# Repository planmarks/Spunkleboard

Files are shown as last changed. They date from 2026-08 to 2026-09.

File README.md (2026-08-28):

# Spunkleboard

**Spunkleboard** is a compact, hackable **ESP32-C3 / ESP32-C5 development board** with everything you
need for portable, interactive projects built in: **6 buttons**, a **0.96" OLED display**, an
onboard **LiPo battery** with charging, and an **SMA antenna connector** for serious wireless range.

It's a blank canvas. Flash it with whatever you like — the hardware is general-purpose and
firmware-agnostic. **Pre-made firmwares are coming soon.**

---

## ✨ Highlights

- 🧠 **ESP32-C3 / ESP32-C5** RIS-V Wi-Fi + Bluetooth LE SoC
- 🕹️ **6 tactile buttons** — a full directional + action pad for menus, games, and UIs
- 🖥️ **0.96" 128×64 OLED** (SSD1306/SSD1315, I²C) — crisp monochrome graphics and text
- 🔋 **Onboard LiPo battery + charging** — go fully untethered
- 📡 **SMA connector** — attach an external antenna for extended Wi-Fi/BLE (and sub-GHz on C5) range
- 🔌 **USB-C** for programming, power, and serial
- 🧩 **Firmware-agnostic** — Arduino, ESP-IDF, MicroPython, and more

---

## 🛠️ Hardware Overview

| Component | Details |
|---|---|
| **MCU module** | Seeed XIAO ESP32-C3 or ESP32-C5 (RISC-V, Wi-Fi + BLE) |
| **Display** | 0.96" OLED, 128×64, monochrome, I²C (`0x3C`) |
| **Buttons** | 6× momentary tactile switches (e.g. Up / Down / Left / Right / OK / Back) |
| **Power** | Single-cell LiPo with onboard charging via USB-C |
| **Antenna** | SMA connector for an external antenna |
| **Interface** | USB-C (power / flashing / serial), exposed GPIO |

> The board accepts the pin-compatible **XIAO ESP32-C3** and **ESP32-C5** modules, so you can pick
> the SoC that fits your project. The C5 adds dual-band Wi-Fi (2.4 + 5 GHz), which pairs nicely with
> the SMA antenna option.

---

## Button Wiring

| Function | Button | XIAO pin | GPIO |
|---|---|---|---|
| Up / Feed | UP | D0 | 1  |
| Down / Play | DOWN  | D1 | 0  |
| OK / Pet | OK | D2 | 25 |
| Back | BACK  | D3 | 7  |
| Left (screen)  | LEFT  | D8 | 8  |
| Right (screen) | RIGHT | D9 | 9  |

---

## 💡 What You Can Build

Because it's just a well-equipped ESP32 board, the possibilities are wide open:

- 📶 **Wi-Fi / BLE tools** — scanners, signal meters, and network utilities (great with the SMA antenna)
- 🎮 **Handheld games & toys** — the 6-button pad + OLED make a natural tiny game console
- 📟 **Portable dashboards** — sensor readouts, clocks, timers, notifiers
- 🏠 **Remote controls & IoT nodes** — battery-powered, wireless, pocket-sized
- 🧪 **Learning & prototyping** — a friendly platform for exploring embedded development
- 🎛️ **Menu-driven gadgets** — anything that benefits from a screen and buttons

---

## 🚀 Getting Started

### 1. Install a toolchain

**Arduino IDE**
1. Add the ESP32 board package (Espressif) via **Boards Manager**.
2. Select the matching **XIAO ESP32-C3** or **XIAO ESP32-C5** board.
3. Install a display library such as **U8g2** for the OLED.

**ESP-IDF** (advanced)
- Set the target with `idf.py set-target esp32c3` (or `esp32c5`) and build/flash as usual.

### 2. Flash

1. Connect the board over **USB-C**.
2. Select the correct serial port.
3. Upload your sketch/firmware. If needed, hold the module's **BOOT** button while connecting to
   enter download mode.

### 3. Hello, board

A first sketch typically:
- Brings up the OLED over I²C (`Wire.begin()`),
- Reads the 6 buttons (configured as `INPUT_PULLUP`, active-LOW),
- Draws a simple menu you can navigate.

---

## 🎛️ Using the Peripherals

- **Buttons** are wired between a GPIO and GND — enable the internal pull-ups (`INPUT_PULLUP`) and
  treat a LOW reading as "pressed."
- **OLED** is on the default I²C bus (SDA/SCL); most 0.96" modules use address `0x3C`.
- **LiPo battery** charges from USB-C; use a protected single-cell pack and mind polarity.
- **SMA antenna** connects to the module's RF path — fit an antenna rated for your band (2.4 GHz for
  C3; 2.4/5 GHz for C5) before transmitting.

> Exact GPIO assignments depend on your board revision and chosen module — check the silkscreen and
> your board's pin map, and consult the Seeed XIAO pin-multiplexing reference for the module you use.

---

## 📦 Firmware

**Pre-made firmwares are coming soon** — ready-to-flash images that showcase what Spunkleboard can do
out of the box. Until then, bring your own: any ESP32-C3/C5 project that uses an I²C OLED, GPIO
buttons, and (optionally) the battery and antenna will run happily here.

Want to share what you've built? Contributions and firmware submissions are welcome.

---

## 🤝 Contributing

Issues, ideas, hardware notes, and firmware contributions are all welcome. Open an issue or a pull
request to get involved.

---

## 📄 License

See the `LICENSE` file for details.

---

*Spunkleboard — a little board with a screen, some buttons, a battery, and an antenna. Make it do
something fun.*

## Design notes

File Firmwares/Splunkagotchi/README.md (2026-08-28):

# Splunkagotchi 🐾📡

A pocket **dual-band Wi-Fi + BLE wardriving rig that is also a Tamagotchi**, for the
**Seeed Studio XIAO ESP32-C5** with a 0.96" OLED and 6 buttons.

Your creature earns XP from every **unique** discovery it makes as you walk around —
Wi-Fi access points (2.4 GHz *and* 5 GHz), BLE devices, and Wi-Fi client stations
picked up by the passive monitor. Captures are logged to an on-device ring buffer.
Feed it, play with it, and watch it grow from an egg into an Elder — leveling is
infinite, and higher stages unlock new sensing abilities.

> The ESP32-C5 is Espressif's first dual-band chip, which is why real 5 GHz scanning
> is possible here — most ESP32 boards are 2.4 GHz only.

---

## ⚖️ Scope & responsible use — please read

This firmware is **passive by design**. It:
- listens to Wi-Fi beacons and BLE advertisements (the same info your phone's Wi-Fi
  list shows), and
- in monitor mode, **observes** over-the-air 802.11 frames to count packets and
  collect device MAC addresses.

It does **not**, and intentionally **cannot**:
- transmit deauthentication frames or perform any denial-of-service ("deauth attack"),
- inject or forge packets,
- connect to or authenticate against foreign networks,
- capture or store packet payloads/contents.

**There is deliberately no deauth/attack capability in this project.** A roaming device
that knocks other people's gear off their networks is an indiscriminate attack on third
parties, so it's out of scope. The "Promiscuous" unlock here is a *passive client
harvester*, not an attack tool. Operate only where passive monitoring is lawful, and
don't store or share data you shouldn't.

---

## Hardware & wiring

| Function | Button | XIAO pin | GPIO |
|---|---|---|---|
| Up / Feed | UP | D0 | 1  |
| Down / Play | DOWN  | D1 | 0  |
| OK / Pet | OK | D2 | 25 |
| Back | BACK  | D3 | 7  |
| Left (screen)  | LEFT  | D8 | 8  |
| Right (screen) | RIGHT | D9 | 9  |

- **Buttons:** each connects its pin to **GND** (internal pull-ups, active-low — no
  resistors).
- **OLED (SSD1306, I²C):** `VCC`→3V3, `GND`→GND, `SDA`→**D4 (GPIO23)**, `SCL`→**D5
  (GPIO24)**, address `0x3C` (some are `0x3D`). Display is flipped 180° in firmware
  (`OLED_ROTATION` in `config.h`).

Pins and every tunable live in [`config.h`](config.h).

---

## Software setup (Arduino IDE)

1. **Boards Manager URL** (*File → Preferences*):
   ```
   https://raw.githubusercontent.com/espressif/arduino-esp32/gh-pages/package_esp32_index.json
   ```
   Install **esp32 by Espressif Systems**, **v3.1.0+** (needed for C5, 5 GHz, and
   promiscuous monitor).
2. **Board:** *Tools → Board → esp32 →* **XIAO_ESP32C5**.
3. **Partition scheme:** pick one with a decent filesystem, e.g. *"Default 4MB with
   spiffs (1.2MB APP / 1.5MB SPIFFS)"*. The capture ring buffer + uniqueness sets need
   room in LittleFS (default ring ≈ 6000 records; see `RECORD_CAP`).
4. **Libraries** (*Manage Libraries*): `Adafruit SSD1306`, `Adafruit GFX Library`,
   `NimBLE-Arduino` (v2.x).
5. Open `xiaoesp32c5_tamagotchi.ino` (keep `config.h` and `names.h` alongside it),
   select the port, **Upload**. Serial monitor at **115200 baud**.

On first boot the pet is given a **random, unique name** generated from the board's
hardware entropy (e.g. `Byte-Gremlin`), stored in NVS.

---

## Controls

| Screen | LEFT / RIGHT | UP | DOWN | OK | BACK |
|---|---|----|---|----|---|
| **Home** | switch screen | Feed | Play | Pet (interact) | Home |
| **Pet** (name/H·M·E/age) | switch screen | — | — | open Menu | Home |
| **Stats** (lifetime totals) | switch screen | — | — | open Menu | Home |
| **Menu** | switch screen | up | down | select | Home |

**Menu:** Feed · Play · Pet · Scan ON/OFF · *Pkt Monitor* (Teen+) · *Promisc Harvest*
(Adult+) · Config (serial) · Save now · Reset pet (OK twice to confirm).

---

## Gameplay

**XP per unique discovery** (tunable in `config.h`):
| Discovery | XP |
|---|----|
| Wi-Fi AP (2.4 or 5 GHz) | 10 |
| BLE device | 8 |
| Wi-Fi client station (monitor) | 12 |
| Packets observed | +1 per 25 frames |

**Leveling is infinite** — each level needs **15% more XP** than the last
(`xpToNext = 100 × 1.15^level`).

**Evolution stages & unlocks** (one new stage every 5 levels, animated 2-frame idle):
| Stage | Levels | Unlocks |
|---|---|---|
| Egg | 0–4 | — |
| Baby  | 5–9 | — |
| Teen  | 10–14 | **Packet Monitoring** |
| Adult | 15+ | **Promiscuous Harvest** |

**Stats:**
- **Hunger** = *satiation* (100 = well fed). Discoveries raise it; it slowly falls when
  nothing is found. Feeding from the menu tops it up.
- **Energy** is restored by discoveries at a rate that depends on hunger: 0–25% hunger
  → no restore, 25–50% → 75%, 50–75% → 100%, 75–100% → 125%. Monitor/promiscuous modes
  drain **1% energy per 5 s**; at 0 energy the pet "sleeps" and returns to normal
  scanning. Play also costs energy.
- **Mood** = 25% from petting/interaction + 75% from discoveries & hunger. Below 25% the
  creature looks sad.
- **Age** is accumulated powered-on lifetime (persists across reboots) and auto-scales
  its unit: minutes → hours (>60 m) → days (>24 h) → months (>30 d) → years (>12 mo).

The creature **talks** — random lines when greeted, fed, played with, petted, on
level-up, and when hungry/sleepy.

---

## On-device storage (ring buffer)

Every unique capture is appended to `/captures.bin` in LittleFS as a fixed-size record:

```
timestamp_s, type(AP2G/AP5G/BLE/CLIENT), mac, rssi, channel, ssid
```

When the buffer fills (`RECORD_CAP`), the **oldest record is overwritten**. Uniqueness
sets survive reboots (stored in LittleFS) so XP isn't re-awarded for the same devices.

---

## Serial console (115200 baud)

Type a command + Enter:

| Cmd | Action |
|-----|---|
| `i` | status / info |
| `w <ssid> <pass>` | set home Wi-Fi (for the future Wigle sync) |
| `k <apiname> <token>` | set Wigle API name + token |
| `n <name>` | rename the pet |
| `d` | dump the capture log as CSV (oldest first) |
| `s` | save state now |
| `c` | clear capture storage |
| `x` | reset the pet (wipes progress + logs) |
| `h` | help |

---

## Wigle upload — deferred (needs GPS)

Wigle.net keys uploads on **GPS coordinates**, and this board has no GPS, so the
uploader is turned **off** (`ENABLE_WIGLE_UPLOAD 0`). The plumbing is in place: your
home-Wi-Fi and Wigle API credentials are captured over serial and stored in NVS, and
captures are already logged locally. When you add a GPS module (UART NMEA), the next
step is: parse coordinates into each record, connect to home Wi-Fi when in range, and
POST the CSV to Wigle's file-upload API. Say the word and I'll wire that up.

---

## Tuning

All gameplay, scan, monitor, XP, level, stat, and storage parameters live in
[`config.h`](config.h). Feature toggles: `ENABLE_5G`, `ENABLE_BLE`, `ENABLE_MONITOR`,
`ENABLE_WIGLE_UPLOAD`.

## Notes & limits
- Wi-Fi and BLE are **time-sliced**, not simultaneous — stable coexistence on the
  single-core C5. Monitor mode is a separate radio mode that pauses normal scanning.
- Monitor/promiscuous channel-hop the **2.4 GHz** band (client activity lives there);
  5 GHz monitor isn't included.
- Client "devices" are transmitter MACs seen in management/data frames; many modern
  phones randomize their MAC, so counts reflect observed addresses, not unique humans.

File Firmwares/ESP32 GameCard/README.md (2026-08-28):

# Gamecard

A pocket game console for the **Seeed XIAO ESP32-C3** with a 0.96" OLED, six
buttons, and a LiPo battery. Single-player games plus multiplayer over
**ESP-NOW** — a host advertises a lobby and nearby units running this firmware
join it.

## Hardware

| Part | Detail |
|---|---|
| MCU | XIAO ESP32-C3 |
| Display | 0.96" SSD1306 OLED, 128×64, I2C @ `0x3C` |
| Buttons | 6× tactile, wired **GPIO → button → GND** |
| Power | 3V LiPo on the XIAO's BAT pads |

### Pin map (XIAO ESP32-C3)

| Function  | Silk | GPIO |
|---|---|---|
| OLED SDA  | D4 | 6 |
| OLED SCL  | D5 | 7 |
| UP | D0 | 2 |
| DOWN | D1 | 3 |
| OK (A) | D2 | 4 |
| BACK (B)  | D3 | 5 |
| LEFT | D8 | 8 |
| RIGHT | D9 | 9 |

Buttons use the internal pull-ups (`INPUT_PULLUP`), so each button just needs to
short its GPIO to GND — no external resistors.

> **Boot caution:** D0/D8/D9 (GPIO2/8/9) are ESP32-C3 *strapping* pins, and
> GPIO9 is the BOOT pin. Because buttons are active-low, holding **RIGHT** (and
> ideally UP/LEFT) while powering on or resetting can put the chip into download
> mode instead of running the sketch. Just don't hold those during reset.

> If your OLED shows nothing, try address `0x3D` in `common.h` (`OLED_ADDR`).

## Build / flash

- **Board:** *XIAO_ESP32C3* (install "esp32 by Espressif" boards, **v3.x**).
- **Libraries:** *Adafruit GFX* and *Adafruit SSD1306* (Library Manager).
- Open `gamecard.ino` in the Arduino IDE (it pulls in the other `.ino` files in
  this folder automatically), select the board/port, and Upload.

The ESP-NOW receive callback is written for Arduino-ESP32 **core 3.x** but falls
back to the 2.x signature automatically.

## Controls

- **Menus:** UP/DOWN move (the list scrolls), **A** select, **B** back.
- **B** quits any game back to the menu; on a game-over screen **A** replays.

## Games

Single-player:

| Game | Controls |
|---|---|
| **Snake** | D-pad to steer |
| **Tetris** | LEFT/RIGHT move, **A** rotate, DOWN soft drop, UP hard drop |
| **2048** | D-pad slides tiles |
| **Runner** | **A**/UP to jump obstacles (endless) |
| **Breakout** | LEFT/RIGHT move paddle |
| **Invaders** | LEFT/RIGHT move, **A** shoot |
| **Minesweeper** | D-pad move cursor, tap **A** reveal, **hold A** to flag |
| **Simon** | Watch the flashing pads, repeat with the D-pad |

Multiplayer:

- **Pong** — `1 Player` (vs CPU), `Host Game`, or `Join Game` (2 players).
- **Tron** — light-cycles for **2-4 players**. `Host Game` opens a lobby; other
  units `Join Game`. The host presses **A** to start once at least one player has
  joined. Steer with the D-pad (no reversing); the ring marks your own cycle.
  Last one riding wins.
- **Battleship** — **2 players**. Each unit hides its own 8x8 fleet (the two
  private screens are the whole point). Placement: D-pad reshuffles a random
  layout, **A** = ready. Battle: D-pad moves the radar cursor, **A** fires. Sink
  the enemy fleet first.
- **Uno** — **2-4 players**. Standard deck and rules (skip, reverse, +2, wild,
  wild +4). On your turn, LEFT/RIGHT pick a card or the **DRAW** slot, **A** to
  confirm; a wild then asks for a colour via the D-pad. First to empty their hand
  wins.

## Multiplayer (ESP-NOW)

1. On one unit: **Pong → Host Game**. It advertises a lobby using its device
   name.
2. On another unit: **Pong → Join Game**. It lists nearby lobbies; pick one and
   press **A**.
3. The host accepts and both drop into a match. The **host** simulates the ball
   and left paddle; the **client** controls the right paddle and renders the
   host's authoritative state.

All units stay on the default WiFi channel (they never join an access point), so
no channel setup is needed. Traffic is tagged with a magic byte so foreign
ESP-NOW packets are ignored.

## Device name

Each unit has a unique name (defaults to `GC-XXXX` from its MAC). Change it in
**Settings**: LEFT/RIGHT move the cursor, UP/DOWN change the character, **A**
saves (persisted in NVS), **B** cancels. The name is what other units see when
browsing lobbies (up to 10 characters).

## Files

| File | Role |
|---|---|
| `gamecard.ino` | globals, `setup`/`loop`, scrolling menu + registry|
| `common.h` | shared declarations |
| `input.ino` | button debounce / edge detection / auto-repeat |
| `settings.ino` | device name editor + NVS persistence |
| `netplay.ino`  | ESP-NOW lobby + transport |
| `snake.ino` | Snake |
| `tetris.ino` | Tetris |
| `g2048.ino` | 2048 |
| `runner.ino` | endless jumper |
| `breakout.ino` | Breakout |
| `invaders.ino` | Space Invaders |
| `mines.ino` | Minesweeper |
| `simon.ino` | Simon |
| `pong.ino` | Pong (single + multiplayer) |
| `netmp.ino` | multiplayer transport (up to 4 players) |
| `mplobby.ino`  | generic host/join lobby for turn-based games |
| `tron.ino` | Tron light-cycles (2-4 players) |
| `bship.ino` | Battleship (2 players) |
| `uno.ino` | Uno (2-4 players) |

## Adding a single-player game

1. Write `myGameInit()` / `myGameUpdate()` in a new `.ino` and declare them in
   `common.h`. The update fn returns to the menu with `setState(ST_MENU)`.
2. Add a launch shim + registry row in `gamecard.ino`:
   `static void L_mine(){ startGame(myGameInit, myGameUpdate); }` and a
   `{ "My Game", L_mine }` entry in `GAMES[]`.

Because all `.ino` files compile into one translation unit, give every
file-scope `static` a game-specific name (e.g. `tScore`, not `score`) to avoid
collisions.

## Multiplayer architecture

Two transport layers share the ESP-NOW radio and the `NET_ADV` lobby discovery:

- **Pong** (`netplay.ino`) — the original 1-host/1-client path.
- **Up to 4 players** (`netmp.ino`) — 1 host + up to 3 clients. Two styles share
  it:
  - *Real-time* (Tron): host is authoritative and **broadcasts** compact state
    each tick; clients unicast input back.
  - *Turn-based* (Battleship, Uno): a generic `NET_MMSG` carries per-game
    messages (`p[]` + a 40-byte `d[]` for things like Uno hands), addressed
    host↔client, delivered through a small receive queue (`mpPoll`). Battleship
    is peer-to-peer shot/reply; Uno is host-as-dealer with private hands.

  Messages carry a player-slot id, and receivers filter by game id + the peer's
  MAC so two nearby games don't cross wires. Turn-based exchanges resend on a
  timer (and Uno re-broadcasts state every 700 ms) so one lost packet can't
  deadlock a turn.

## Roadmap

More games on the `netmp.ino` layer: a trivia/reaction buzzer and Connect 4 are
natural next additions.

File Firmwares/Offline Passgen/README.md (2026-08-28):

# PIGEON — Private Independent Generator & Encrypted Offline Notebook

An **offline** secure password generator and encrypted vault built on the
Seeed Studio **XIAO ESP32-C3**, a 0.96" SSD1306 OLED, and 6 push buttons.

The device never starts WiFi or Bluetooth. Passwords are generated with the
ESP32-C3 hardware RNG and stored **encrypted** in flash. Nothing readable is
written to flash without your master PIN.

---

## Hardware

| Part | Notes |
|---|---|
| Seeed XIAO ESP32-C3 | Target MCU |
| 0.96" OLED, SSD1306 | 128×64, I²C, address `0x3C` |
| 6× momentary buttons | Active-low, wired to GND |

### Button wiring

| Pin | Function |
|-----|---|
| D0  | UP |
| D1  | DOWN |
| D2  | OK |
| D3  | BACK |
| D8  | LEFT |
| D9  | RIGHT  |

Each button connects its pin to **GND**. Internal pull-ups are enabled in
firmware (`INPUT_PULLUP`), so no external resistors are needed.

> **Note:** D8 (GPIO8) and D9 (GPIO9) are ESP32-C3 strapping/boot pins. A plain
> button to GND is fine at runtime, but do **not** hold LEFT/RIGHT down while
> powering on/flashing — that can interfere with boot mode. GPIO9 doubles as the
> BOOT button.

### OLED wiring (XIAO ESP32-C3 default I²C)

| OLED | XIAO |
|---|---|
| SDA  | D4 (GPIO6) |
| SCL  | D5 (GPIO7) |
| VCC  | 3V3 |
| GND  | GND |

---

## Building / flashing (Arduino IDE)

1. Install the **ESP32 board package** (Boards Manager → "esp32" by Espressif).
2. Install libraries (Library Manager):
   - **Adafruit GFX Library**
   - **Adafruit SSD1306**
   - (`Preferences` and mbedTLS ship with the ESP32 core.)
3. Open `PIGEON - Password Generator.ino`.
4. Select board: **XIAO_ESP32C3**. Choose the correct COM port.
5. Upload.

---

## Security design

- **Master PIN** (4–8 digits) gates the device and is never stored.
- A 32-byte **AES-256 key** is derived from PIN + a per-device random 16-byte
  salt using **PBKDF2-HMAC-SHA256** (20,000 iterations).
- The flash stores only `salt` and a **verifier** = `SHA-256(AES key)`. The key
  itself is never persisted, so dumping flash cannot recover it without the PIN.
- Each vault entry is encrypted with **AES-256-CBC** using a fresh random IV.
- Wrong-PIN attempts trigger a growing delay to slow brute-forcing.
- **Change PIN** transparently re-encrypts the whole vault under the new key.
- **Factory reset** wipes PIN, vault, and settings.

> This is a hobbyist cold-storage aid, not a certified secure element. The AES
> key exists in RAM while unlocked, and flash is not read-protected against a
> determined physical attacker with chip-level access. Use a strong PIN, and
> lock the device when idle.

---

## Controls

**PIN entry:** UP/DOWN change the current digit · RIGHT adds it · LEFT deletes ·
OK submits.

**Text entry** (labels/usernames/manual passwords): LEFT/RIGHT move by one
character, UP/DOWN jump by five · OK picks · BACK backspaces · select `<DONE>`
then OK to finish.

**Menus:** UP/DOWN move · OK select · BACK exit.

### Menu map

- **Generate** — set length (8–63) and character sets (abc / ABC / 123 / !@#),
  then generate. On the result screen, OK saves it to the vault, BACK exits.
- **Vault** — browse stored entries by label; LEFT/RIGHT flip between username
  and password; OK offers delete.
- **Add entry** — enter label + username, then generate or type a password.
- **Settings** — Change PIN · Lock now · Factory reset · About.
- **Lock** — clears the key from RAM and returns to the PIN screen.

---

## First run

On first boot you'll be asked to set a master PIN (entered twice). After that,
every power-up requires the PIN before anything else is accessible.

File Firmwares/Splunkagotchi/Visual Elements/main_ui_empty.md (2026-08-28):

// [BEGIN lopaka generated]
#include "Org_01.h"

static const unsigned char PROGMEM image_paint_9_1_bits[] = {0x20,0x30,0xa8,0x70,0x70,0xa8,0x30,0x20};

static const unsigned char PROGMEM image_paint_9_bits[] = {0x3e,0x00,0x41,0x00,0x80,0x80,0x1c,0x00,0x22,0x00,0x00,0x00,0x08,0x00};

void drawScreen_1(void) {
    gfx->fillScreen(0x0);

    // string 2
    gfx->setTextColor(0xFFFF);
    gfx->setTextWrap(false);
    gfx->setCursor(3, 3);
    gfx->println("L");
    // rect 3
    gfx->drawRect(0, 14, 128, 4, 0xFFFF);
    // string 5
    gfx->setCursor(10, 3);
    gfx->println("0");
    // string 8
    gfx->setCursor(14, 21);
    gfx->println("0");
    // string 9
    gfx->setCursor(14, 31);
    gfx->println("0");
    // paint 9
    gfx->drawBitmap(3, 31, image_paint_9_bits, 9, 7, 0xFFFF);
    // paint 9
    gfx->drawBitmap(5, 20, image_paint_9_1_bits, 5, 8, 0xFFFF);
    // string 9
    gfx->setFont(&Org_01);
    gfx->setCursor(5, 45);
    gfx->println("H");
    // string 9 copy 1
    gfx->setCursor(5, 53);
    gfx->println("M");
    // ellipse 12
    gfx->drawEllipse(90, 3, 3, 3, 0xFFFF);
    // string 9 copy 2
    gfx->setCursor(5, 61);
    gfx->println("E");
    // string 13
    gfx->setFont();
    gfx->setCursor(96, 3);
    gfx->println("5G/BT");
    // rect 14
    gfx->drawRect(12, 41, 25, 5, 0xFFFF);
    // rect 14 copy 1
    gfx->drawRect(12, 49, 25, 5, 0xFFFF);
    // rect 14 copy 2
    gfx->drawRect(12, 57, 25, 5, 0xFFFF);
}
// [END lopaka generated]

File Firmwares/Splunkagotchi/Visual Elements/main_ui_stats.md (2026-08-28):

// [BEGIN lopaka generated]
#include "Org_01.h"

static const unsigned char PROGMEM image_paint_9_1_bits[] = {0x20,0x30,0xa8,0x70,0x70,0xa8,0x30,0x20};

static const unsigned char PROGMEM image_paint_9_bits[] = {0x3e,0x00,0x41,0x00,0x80,0x80,0x1c,0x00,0x22,0x00,0x00,0x00,0x08,0x00};

void drawScreen_1(void) {
    gfx->fillScreen(0x0);

    // string 2
    gfx->setTextColor(0xFFFF);
    gfx->setTextWrap(false);
    gfx->setCursor(3, 4);
    gfx->println("L");
    // rect 3
    gfx->drawRect(0, 14, 128, 4, 0xFFFF);
    // string 5
    gfx->setCursor(10, 4);
    gfx->println("21");
    // string 8
    gfx->setCursor(14, 21);
    gfx->println("311");
    // string 9
    gfx->setCursor(14, 31);
    gfx->println("512");
    // paint 9
    gfx->drawBitmap(3, 31, image_paint_9_bits, 9, 7, 0xFFFF);
    // paint 9
    gfx->drawBitmap(5, 20, image_paint_9_1_bits, 5, 8, 0xFFFF);
    // string 9
    gfx->setFont(&Org_01);
    gfx->setCursor(5, 45);
    gfx->println("H");
    // string 9 copy 1
    gfx->setCursor(5, 53);
    gfx->println("M");
    // ellipse 12
    gfx->drawEllipse(90, 4, 3, 3, 0xFFFF);
    // string 9 copy 2
    gfx->setCursor(5, 61);
    gfx->println("E");
    // string 13
    gfx->setFont();
    gfx->setCursor(96, 4);
    gfx->println("5G/BT");
    // rect 14
    gfx->drawRect(12, 41, 25, 5, 0xFFFF);
    // rect 14 copy 1
    gfx->drawRect(12, 49, 25, 5, 0xFFFF);
    // rect 16
    gfx->fillRect(1, 15, 98, 2, 0xFFFF);
    // rect 14 copy 2
    gfx->drawRect(12, 57, 25, 5, 0xFFFF);
    // rect 17
    gfx->fillRect(13, 42, 19, 3, 0xFFFF);
    // rect 18
    gfx->fillRect(13, 50, 14, 3, 0xFFFF);
    // rect 19
    gfx->fillRect(13, 58, 22, 3, 0xFFFF);
}
// [END lopaka generated]

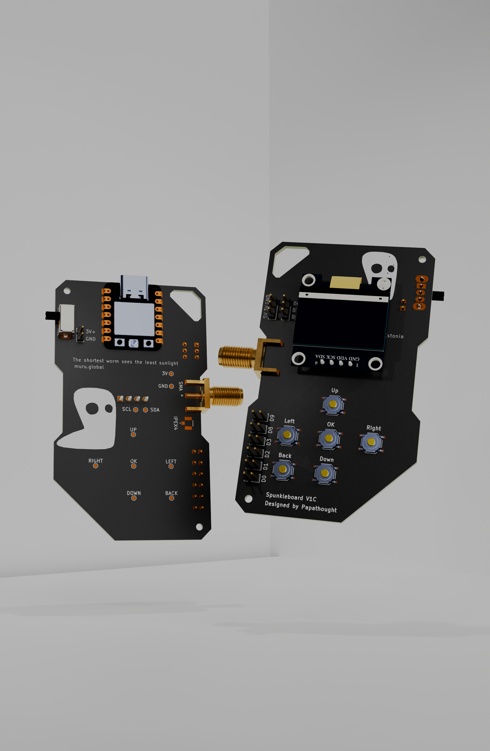
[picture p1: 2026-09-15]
Images/Render-V1C-Whitebg.png

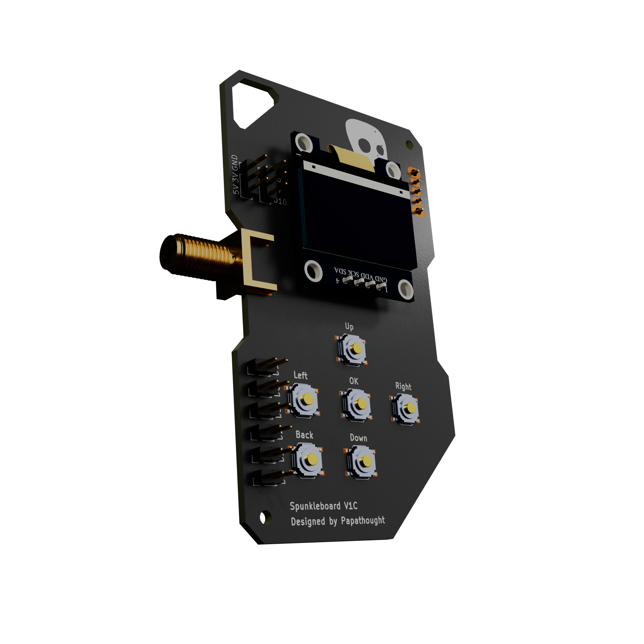
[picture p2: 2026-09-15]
Images/Render-V1C-single-transparentbg.png

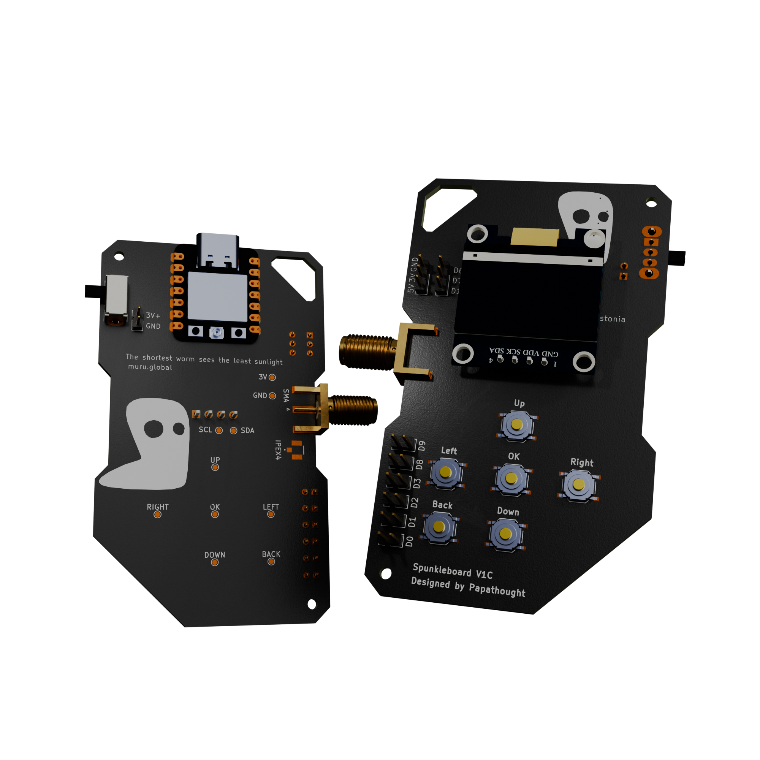
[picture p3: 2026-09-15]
Images/Render-V1C-transparentbg.png

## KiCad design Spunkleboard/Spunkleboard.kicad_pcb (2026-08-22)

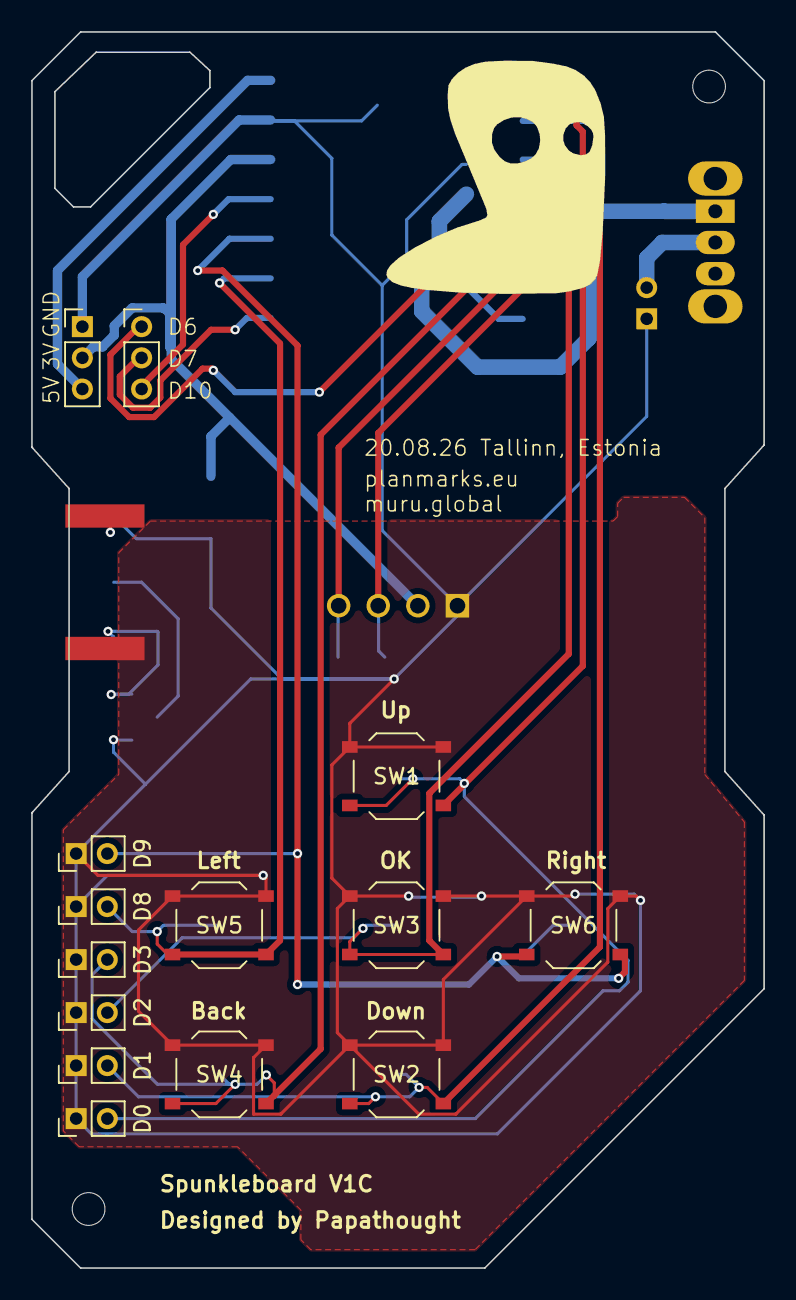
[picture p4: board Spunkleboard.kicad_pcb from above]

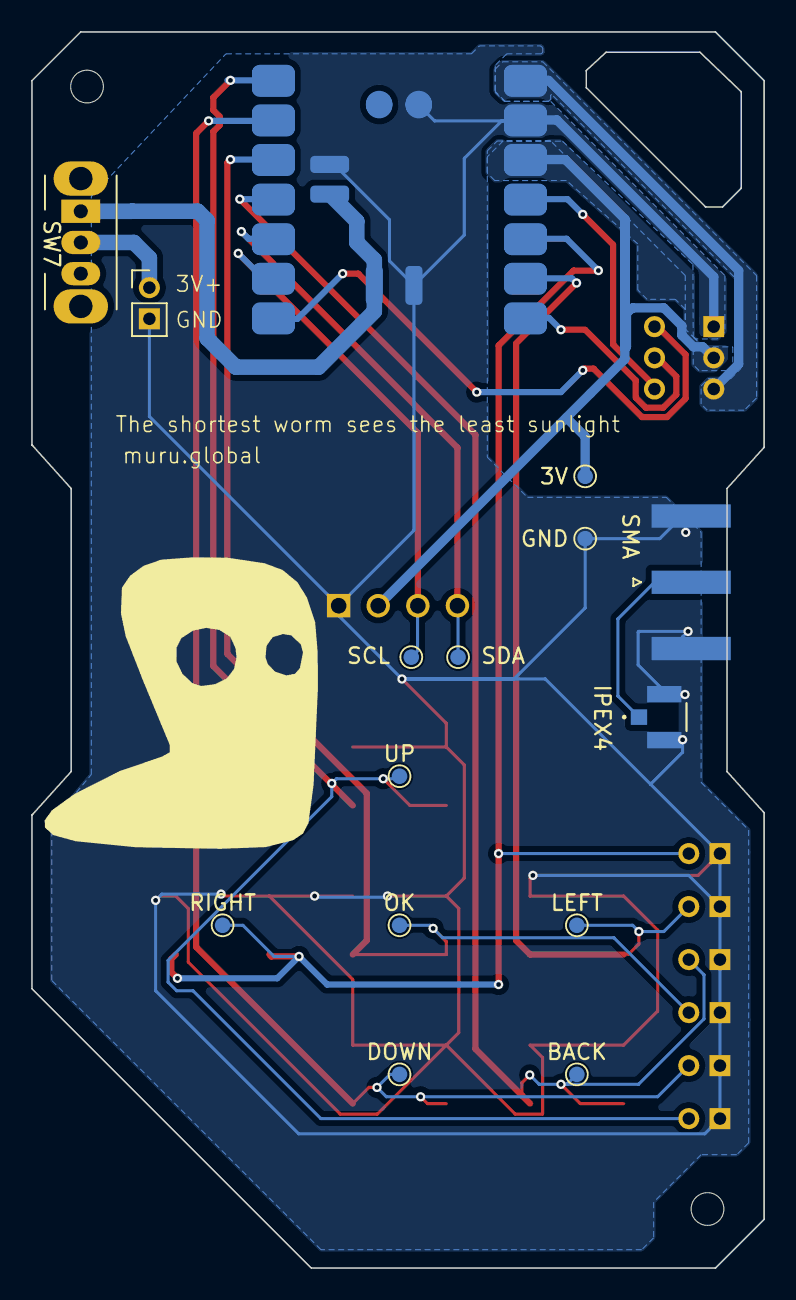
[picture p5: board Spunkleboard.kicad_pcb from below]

Board: 2 copper layers, 47.0 x 79.3 mm, 31 parts (16 on the bottom side), 18 nets.

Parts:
3V: 3V3; TestPoint_Pad_D1.0mm
BACK: SW-BCK; TestPoint_Pad_D1.0mm
BT1: Battery; PinHeader_1x02_P2.00mm_Vertical
D0, D1, D2, D3, D8, D9: PinHeader_1x02_P2.00mm_Vertical
DOWN: SW-DWN; TestPoint_Pad_D1.0mm
GND: GND; TestPoint_Pad_D1.0mm
IPEX4: MHF_I_RECE_IPX; MHF I_RECE_IPX
LEFT: SW-LFT; TestPoint_Pad_D1.0mm
MNT: MountingHole_2.1mm
MNT#2: MountingHole_2.1mm
OK: SW-OK; TestPoint_Pad_D1.0mm
RIGHT: SW-RHT; TestPoint_Pad_D1.0mm
SCL: SCL; TestPoint_Pad_D1.0mm
SDA: SDA; TestPoint_Pad_D1.0mm
SMA: SMA_Amphenol_132289_EdgeMount
SW1: SW_Push UP; SW_Push_1P1T_XKB_TS-1187A
SW2: SW_Push DOWN; SW_Push_1P1T_XKB_TS-1187A
SW3: SW_Push OK; SW_Push_1P1T_XKB_TS-1187A
SW4: SW_Push BACK; SW_Push_1P1T_XKB_TS-1187A
SW5: SW_Push LEFT; SW_Push_1P1T_XKB_TS-1187A
SW6: SW_Push RIGHT; SW_Push_1P1T_XKB_TS-1187A
SW7: SW_SPDT; SW_Slide_SPDT_Angled_CK_OS102011MA1Q
U1: XIAO-ESP32-C5-SMD
U2: DM-OLED096-636; MODULE_DM-OLED096-636
U3: XIAO-ESP32-C3-SMD
UP: SW-UP; TestPoint_Pad_D1.0mm

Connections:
+3.3V: 3V.1 (1_1), U1.12 (3V3_OUT), U2.2 (VCC_IN), U3.12 (3V3_OUT)
BAT+: BT1.1 (+), SW7.2 (B)
D0-SW1: D0.2, SW1.2, U1.1 (D0), U3.1 (D0), UP.1 (1_1)
D1-SW2: D1.2, DOWN.1 (1_1), SW2.2, U1.2 (D1), U3.2 (D1)
D2-SW3: D2.2, OK.1 (1_1), SW3.2, U1.3 (D2), U3.3 (D2)
D3-SW4: BACK.1 (1_1), D3.2, SW4.2, U1.4 (D3), U3.4 (D3)
D4-SDA: SDA.1 (1_1), U1.5 (D4), U2.4 (SDA), U3.5 (D4)
D5-SCL: SCL.1 (1_1), U1.6 (D5), U2.3 (SCL), U3.6 (D5)
D6: U1.7 (D6), U3.7 (D6)
D7: U1.8 (D7), U3.8 (D7)
D8-SW5: D8.2, LEFT.1 (1_1), SW5.2, U1.9 (D8), U3.9 (D8)
D9-SW6: D9.2, RIGHT.1 (1_1), SW6.2, U1.10 (D9), U3.10 (D9/BOOT)
D10: U1.11 (D10), U3.11 (D10)
EN: U1.17 (EN), U3.17 (EN)
GND: BT1.2 (-), D0.1, D1.1, D2.1, D3.1, D8.1, D9.1, GND.1 (1_1), IPEX4.1, IPEX4.2, SMA.2, SW1.1, SW2.1, SW3.1, SW4.1, SW5.1, SW6.1, U1.13 (GND), U1.18 (GND), U1.24 (GND), U2.1 (GND), U3.13 (GND), U3.18 (GND), U3.22 (GND)
IPEX: IPEX4.3, SMA.1
VBAT: SW7.1 (A), U1.23 (VBAT), U3.21 (VBAT)
VBUS: U1.14 (VBUS), U3.14 (VBUS)

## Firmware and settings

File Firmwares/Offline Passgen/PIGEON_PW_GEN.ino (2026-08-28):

/*
 * ============================================================================
 *  PIGEON  -  Private Independent Generator & Encrypted Offline Notebook
 * ============================================================================
 *  Offline secure password generator + encrypted vault.
 *
 *  Target board : Seeed Studio XIAO ESP32-C3
 *  Display      : 0.96" OLED, SSD1306, 128x64, I2C @ 0x3C
 *  Inputs       : 6 momentary push buttons (active-low, internal pull-ups)
 *
 *  Button wiring:
 *      D0 -> UP       D1 -> DOWN     D2 -> OK
 *      D3 -> BACK     D8 -> LEFT     D9 -> RIGHT
 *
 *  I2C wiring (XIAO ESP32-C3 default):
 *      D4 (GPIO6) -> OLED SDA
 *      D5 (GPIO7) -> OLED SCL
 *      3V3        -> OLED VCC
 *      GND        -> OLED GND
 *
 *  Security model
 *  --------------
 *  - A master PIN gates the device. The PIN never leaves RAM.
 *  - A 32-byte AES key is derived from the PIN with PBKDF2-HMAC-SHA256
 *    (per-device random 16-byte salt, high iteration count).
 *  - The stored verifier is SHA-256(AES key) -- the key itself is never
 *    written to flash, so a flash dump cannot reveal it without the PIN.
 *  - Each vault entry is encrypted with AES-256-CBC using a fresh random IV.
 *  - Randomness comes from the ESP32-C3 hardware RNG (esp_random()).
 *  - The device is fully offline: WiFi and Bluetooth are never started.
 *
 *  Libraries required (install via Arduino Library Manager):
 *      - Adafruit GFX Library
 *      - Adafruit SSD1306
 *  (mbedTLS and Preferences ship with the ESP32 Arduino core.)
 * ============================================================================
 */

#include <Wire.h>
#include <Adafruit_GFX.h>
#include <Adafruit_SSD1306.h>
#include <Preferences.h>

#include "esp_random.h"
#include "mbedtls/aes.h"
#include "mbedtls/md.h"
#include "mbedtls/sha256.h"
#include "mbedtls/pkcs5.h"

// ---------------------------------------------------------------------------
//  Display
// ---------------------------------------------------------------------------
#define SCREEN_WIDTH  128
#define SCREEN_HEIGHT 64
#define OLED_RESET    -1
#define OLED_ADDR     0x3C
Adafruit_SSD1306 display(SCREEN_WIDTH, SCREEN_HEIGHT, &Wire, OLED_RESET);

// ---------------------------------------------------------------------------
//  Buttons
// ---------------------------------------------------------------------------
#define BTN_UP    D0
#define BTN_DOWN  D1
#define BTN_OK    D2
#define BTN_BACK  D3
#define BTN_LEFT  D8
#define BTN_RIGHT D9

enum Event : int8_t {
  EV_NONE = -1,
  EV_UP   = 0,
  EV_DOWN,
  EV_OK,
  EV_BACK,
  EV_LEFT,
  EV_RIGHT,
  EV_OK_LONG,     // OK held past LONG_MS
  EV_BACK_LONG    // BACK held past LONG_MS
};

const uint8_t kBtnPins[6] = { BTN_UP, BTN_DOWN, BTN_OK, BTN_BACK, BTN_LEFT, BTN_RIGHT };
static bool     btnState[6]    = { false };
static uint32_t btnRepeat[6]   = { 0 };
static uint32_t btnDownTime[6] = { 0 };
static bool     btnLongFired[6]= { false };

// Auto-repeat timing (ms) for directional keys held down.
static const uint32_t REPEAT_DELAY = 420;
static const uint32_t REPEAT_RATE  = 110;
// Hold time (ms) that turns an OK/BACK tap into a long-press.
static const uint32_t LONG_MS      = 550;

// ---------------------------------------------------------------------------
//  Crypto / storage parameters
// ---------------------------------------------------------------------------
static const uint32_t PBKDF2_ITERS = 20000;
static const uint8_t  SALT_LEN     = 16;
static const uint8_t  IV_LEN       = 16;
static const uint8_t  KEY_LEN      = 32;   // AES-256
static const uint8_t  VERIF_LEN    = 32;   // SHA-256

// Fixed-size plaintext record. Total MUST be a multiple of 16 (AES block).
#define LBL_LEN  24
#define USR_LEN  32
#define PWD_LEN  64
struct Entry {
  char label[LBL_LEN];
  char user[USR_LEN];
  char pass[PWD_LEN];
  char pad[8];        // -> 24+32+64+8 = 128 bytes
};
static const uint16_t ENTRY_PLAIN = sizeof(Entry);       // 128
static const uint16_t ENTRY_BLOB  = IV_LEN + ENTRY_PLAIN; // 144

static uint8_t g_aesKey[KEY_LEN];   // live only while unlocked
static bool    g_unlocked = false;

// ---------------------------------------------------------------------------
//  Generator configuration (non-secret, persisted in NVS)
// ---------------------------------------------------------------------------
struct GenCfg {
  uint8_t length;
  bool    useLower;
  bool    useUpper;
  bool    useDigits;
  bool    useSymbols;
};
static GenCfg g_cfg = { 20, true, true, true, true };

static const char* CS_LOWER   = "abcdefghijklmnopqrstuvwxyz";
static const char* CS_UPPER   = "ABCDEFGHIJKLMNOPQRSTUVWXYZ";
static const char* CS_DIGITS  = "0123456789";
static const char* CS_SYMBOLS = "!@#$%^&*()-_=+[]{};:,.?/";

// ===========================================================================
//  Low level helpers
// ===========================================================================
static void fillRandom(uint8_t* buf, size_t n) {
  size_t i = 0;
  while (i < n) {
    uint32_t r = esp_random();
    size_t c = (n - i < 4) ? (n - i) : 4;
    memcpy(buf + i, &r, c);
    i += c;
  }
}

// Uniform integer in [0, range) using rejection sampling (no modulo bias).
static uint32_t randBelow(uint32_t range) {
  if (range == 0) return 0;
  uint32_t limit = UINT32_MAX - (UINT32_MAX % range);
  uint32_t r;
  do { r = esp_random(); } while (r >= limit);
  return r % range;
}

static void pbkdf2(const char* pw, const uint8_t* salt, size_t slen,
                   uint32_t iters, uint8_t* out, size_t olen) {
  // mbedTLS 3.x (ESP32 core 3.x): context-free API.
  mbedtls_pkcs5_pbkdf2_hmac_ext(MBEDTLS_MD_SHA256,
                                (const uint8_t*)pw, strlen(pw),
                                salt, slen, iters, olen, out);
}

static void sha256(const uint8_t* in, size_t len, uint8_t* out32) {
  mbedtls_sha256(in, len, out32, 0 /* not SHA-224 */);
}

static bool constTimeEqual(const uint8_t* a, const uint8_t* b, size_t n) {
  uint8_t diff = 0;
  for (size_t i = 0; i < n; i++) diff |= (a[i] ^ b[i]);
  return diff == 0;
}

static void encryptEntry(const Entry& e, uint8_t* out /* ENTRY_BLOB */) {
  uint8_t iv[IV_LEN];
  fillRandom(iv, IV_LEN);
  memcpy(out, iv, IV_LEN);

  uint8_t ivWork[IV_LEN];
  memcpy(ivWork, iv, IV_LEN);   // CBC mutates the IV buffer

  mbedtls_aes_context aes;
  mbedtls_aes_init(&aes);
  mbedtls_aes_setkey_enc(&aes, g_aesKey, 256);
  mbedtls_aes_crypt_cbc(&aes, MBEDTLS_AES_ENCRYPT, ENTRY_PLAIN,
                        ivWork, (const uint8_t*)&e, out + IV_LEN);
  mbedtls_aes_free(&aes);
}

static void decryptEntry(const uint8_t* blob /* ENTRY_BLOB */, Entry& e) {
  uint8_t ivWork[IV_LEN];
  memcpy(ivWork, blob, IV_LEN);

  mbedtls_aes_context aes;
  mbedtls_aes_init(&aes);
  mbedtls_aes_setkey_dec(&aes, g_aesKey, 256);
  mbedtls_aes_crypt_cbc(&aes, MBEDTLS_AES_DECRYPT, ENTRY_PLAIN,
                        ivWork, blob + IV_LEN, (uint8_t*)&e);
  mbedtls_aes_free(&aes);
}

// ===========================================================================
//  Vault (NVS namespace "vault")
// ===========================================================================
static uint32_t vaultCount() {
  Preferences p;
  p.begin("vault", true);
  uint32_t n = p.getUInt("cnt", 0);
  p.end();
  return n;
}

static bool vaultLoad(uint32_t idx, Entry& e) {
  char key[8];
  snprintf(key, sizeof(key), "e%lu", (unsigned long)idx);
  uint8_t blob[ENTRY_BLOB];
  Preferences p;
  p.begin("vault", true);
  size_t got = p.getBytes(key, blob, ENTRY_BLOB);
  p.end();
  if (got != ENTRY_BLOB) return false;
  decryptEntry(blob, e);
  return true;
}

static bool vaultStoreRaw(uint32_t idx, const Entry& e) {
  char key[8];
  snprintf(key, sizeof(key), "e%lu", (unsigned long)idx);
  uint8_t blob[ENTRY_BLOB];
  encryptEntry(e, blob);
  Preferences p;
  p.begin("vault", false);
  size_t wrote = p.putBytes(key, blob, ENTRY_BLOB);
  p.end();
  return wrote == ENTRY_BLOB;
}

static bool vaultAdd(const Entry& e) {
  uint32_t n = vaultCount();
  if (!vaultStoreRaw(n, e)) return false;
  Preferences p;
  p.begin("vault", false);
  p.putUInt("cnt", n + 1);
  p.end();
  return true;
}

static void vaultDelete(uint32_t idx) {
  uint32_t n = vaultCount();
  if (idx >= n) return;
  // Compact: shift each later entry down by one slot.
  for (uint32_t i = idx; i + 1 < n; i++) {
    Entry tmp;
    if (vaultLoad(i + 1, tmp)) vaultStoreRaw(i, tmp);
  }
  // Remove the now-duplicate last slot and update the count.
  char key[8];
  snprintf(key, sizeof(key), "e%lu", (unsigned long)(n - 1));
  Preferences p;
  p.begin("vault", false);
  p.remove(key);
  p.putUInt("cnt", n - 1);
  p.end();
}

// ===========================================================================
//  Auth (NVS namespace "auth")
// ===========================================================================
static bool authExists() {
  Preferences p;
  p.begin("auth", true);
  bool has = p.isKey("verif");
  p.end();
  return has;
}

// Derive key from PIN + stored salt, load it into g_aesKey.
static void deriveKeyFromPin(const String& pin) {
  uint8_t salt[SALT_LEN];
  Preferences p;
  p.begin("auth", true);
  p.getBytes("salt", salt, SALT_LEN);
  p.end();
  pbkdf2(pin.c_str(), salt, SALT_LEN, PBKDF2_ITERS, g_aesKey, KEY_LEN);
}

static void authCreate(const String& pin) {
  uint8_t salt[SALT_LEN];
  fillRandom(salt, SALT_LEN);
  pbkdf2(pin.c_str(), salt, SALT_LEN, PBKDF2_ITERS, g_aesKey, KEY_LEN);

  uint8_t verif[VERIF_LEN];
  sha256(g_aesKey, KEY_LEN, verif);

  Preferences p;
  p.begin("auth", false);
  p.putBytes("salt", salt, SALT_LEN);
  p.putBytes("verif", verif, VERIF_LEN);
  p.end();
}

static bool authVerify(const String& pin) {
  deriveKeyFromPin(pin);
  uint8_t verif[VERIF_LEN];
  sha256(g_aesKey, KEY_LEN, verif);

  uint8_t stored[VERIF_LEN];
  Preferences p;
  p.begin("auth", true);
  size_t got = p.getBytes("verif", stored, VERIF_LEN);
  p.end();
  if (got != VERIF_LEN) return false;

  bool ok = constTimeEqual(verif, stored, VERIF_LEN);
  if (!ok) memset(g_aesKey, 0, KEY_LEN);   // wipe wrong key
  return ok;
}

static void factoryReset() {
  Preferences p;
  p.begin("auth", false);  p.clear(); p.end();
  p.begin("vault", false); p.clear(); p.end();
  p.begin("cfg", false);   p.clear(); p.end();
  memset(g_aesKey, 0, KEY_LEN);
  g_unlocked = false;
}

// ===========================================================================
//  Config persistence (NVS namespace "cfg")
// ===========================================================================
static void cfgLoad() {
  Preferences p;
  p.begin("cfg", true);
  g_cfg.length     = p.getUChar("len", 20);
  g_cfg.useLower   = p.getBool("lo", true);
  g_cfg.useUpper   = p.getBool("up", true);
  g_cfg.useDigits  = p.getBool("di", true);
  g_cfg.useSymbols = p.getBool("sy", true);
  p.end();
  if (g_cfg.length < 8)  g_cfg.length = 8;
  if (g_cfg.length > PWD_LEN - 1) g_cfg.length = PWD_LEN - 1;
}

static void cfgSave() {
  Preferences p;
  p.begin("cfg", false);
  p.putUChar("len", g_cfg.length);
  p.putBool("lo", g_cfg.useLower);
  p.putBool("up", g_cfg.useUpper);
  p.putBool("di", g_cfg.useDigits);
  p.putBool("sy", g_cfg.useSymbols);
  p.end();
}

// ===========================================================================
//  Password generation
// ===========================================================================
// Returns false if no character set is enabled.
static bool generatePassword(const GenCfg& cfg, char* out, uint8_t maxLen) {
  char pool[128];
  uint16_t pn = 0;
  if (cfg.useLower)   { strcpy(pool + pn, CS_LOWER);   pn += strlen(CS_LOWER); }
  if (cfg.useUpper)   { strcpy(pool + pn, CS_UPPER);   pn += strlen(CS_UPPER); }
  if (cfg.useDigits)  { strcpy(pool + pn, CS_DIGITS);  pn += strlen(CS_DIGITS); }
  if (cfg.useSymbols) { strcpy(pool + pn, CS_SYMBOLS); pn += strlen(CS_SYMBOLS); }
  if (pn == 0) return false;

  uint8_t len = cfg.length;
  if (len > maxLen - 1) len = maxLen - 1;

  for (uint8_t i = 0; i < len; i++) {
    out[i] = pool[randBelow(pn)];
  }
  out[len] = '\0';
  return true;
}

// ===========================================================================
//  Input: buttons
// ===========================================================================
static int8_t readEvent() {
  int8_t ev = EV_NONE;
  uint32_t now = millis();
  for (int i = 0; i < 6; i++) {
    bool pressed = (digitalRead(kBtnPins[i]) == LOW);
    bool dir = (i == EV_UP || i == EV_DOWN || i == EV_LEFT || i == EV_RIGHT);
    if (pressed && !btnState[i]) {
      btnState[i]     = true;
      btnDownTime[i]  = now;
      btnLongFired[i] = false;
      btnRepeat[i]    = now + REPEAT_DELAY;
      if (dir) ev = i;              // directional: act on press
      // OK/BACK: wait for release to tell a tap from a long-press
    } else if (pressed && btnState[i]) {
      if (dir) {
        if (now >= btnRepeat[i]) { btnRepeat[i] = now + REPEAT_RATE; ev = i; }
      } else if (!btnLongFired[i] && (now - btnDownTime[i] >= LONG_MS)) {
        btnLongFired[i] = true;     // fire the long event once, while still held
        ev = (i == EV_OK) ? EV_OK_LONG : EV_BACK_LONG;
      }
    } else if (!pressed && btnState[i]) {
      btnState[i] = false;          // release
      if (!dir && !btnLongFired[i]) ev = i;   // short tap emitted on release
    }
  }
  delay(6);   // crude debounce
  return ev;
}

// Block until any button is pressed and released.
static void waitAnyKey() {
  while (readEvent() == EV_NONE) {}
}

// ===========================================================================
//  Display helpers
// ===========================================================================
static void header(const char* title) {
  display.fillRect(0, 0, SCREEN_WIDTH, 11, SSD1306_WHITE);
  display.setTextColor(SSD1306_BLACK);
  display.setCursor(2, 2);
  display.print(title);
  display.setTextColor(SSD1306_WHITE);
}

static void toast(const char* line1, const char* line2 = nullptr) {
  display.clearDisplay();
  display.setTextColor(SSD1306_WHITE);
  display.setCursor(0, 22);
  display.setTextSize(1);
  display.println(line1);
  if (line2) { display.setCursor(0, 34); display.println(line2); }
  display.display();
}

// Scrollable list menu. Returns selected index, or -1 on BACK.
static int menu(const char* title, const char* const* items, int count) {
  int sel = 0, top = 0;
  const int rows = 5;   // visible rows below the header
  while (true) {
    display.clearDisplay();
    header(title);
    display.setTextColor(SSD1306_WHITE);
    for (int r = 0; r < rows && (top + r) < count; r++) {
      int idx = top + r;
      int y = 14 + r * 10;
      if (idx == sel) {
        display.fillRect(0, y - 1, SCREEN_WIDTH, 10, SSD1306_WHITE);
        display.setTextColor(SSD1306_BLACK);
      } else {
        display.setTextColor(SSD1306_WHITE);
      }
      display.setCursor(2, y);
      display.print(items[idx]);
    }
    // scroll indicators
    display.setTextColor(SSD1306_WHITE);
    if (top > 0)              display.drawChar(122, 14, 0x18, SSD1306_WHITE, 0, 1);
    if (top + rows < count)   display.drawChar(122, 54, 0x19, SSD1306_WHITE, 0, 1);
    display.display();

    int8_t ev = readEvent();
    if (ev == EV_UP)   { if (sel > 0) sel--; }
    if (ev == EV_DOWN) { if (sel < count - 1) sel++; }
    if (ev == EV_OK)   return sel;
    if (ev == EV_BACK) return -1;
    if (sel < top) top = sel;
    if (sel >= top + rows) top = sel - rows + 1;
  }
}

// Print wrapped text into the body area; simple word-free wrap at char width.
static void drawWrapped(int x, int y, const char* s) {
  const int cw = 6;                       // char width at size 1
  const int maxCols = (SCREEN_WIDTH - x) / cw;
  int col = 0, cy = y;
  for (const char* p = s; *p; p++) {
    if (col >= maxCols) { col = 0; cy += 9; }
    display.setCursor(x + col * cw, cy);
    display.write(*p);
    col++;
  }
}

// ===========================================================================
//  Input: numeric PIN
// ===========================================================================
// Returns "" if cancelled with BACK on an empty buffer.
static String enterPin(const char* title) {
  String buf = "";
  int cur = 0;         // 0..9 current digit
  const int maxLen = 8;
  while (true) {
    display.clearDisplay();
    header(title);
    display.setTextColor(SSD1306_WHITE);

    // masked entered digits
    display.setCursor(4, 20);
    display.setTextSize(2);
    String masked = "";
    for (uint16_t i = 0; i < buf.length(); i++) masked += "*";
    display.print(masked);
    display.setTextSize(1);

    // current digit selector
    display.setCursor(4, 44);
    display.print("Digit: ");
    display.setTextSize(2);
    display.setCursor(56, 40);
    display.print(cur);
    display.setTextSize(1);

    display.setCursor(0, 56);
    display.print("UD:val R:add L:del OK:go");
    display.display();

    int8_t ev = readEvent();
    if (ev == EV_UP)    cur = (cur + 1) % 10;
    if (ev == EV_DOWN)  cur = (cur + 9) % 10;
    if (ev == EV_RIGHT) { if ((int)buf.length() < maxLen) { buf += char('0' + cur); cur = 0; } }
    if (ev == EV_LEFT)  { if (buf.length() > 0) buf.remove(buf.length() - 1); }
    if (ev == EV_OK)    { if (buf.length() >= 4) return buf; toast("PIN too short", "min 4 digits"); display.display(); delay(700); }
    if (ev == EV_BACK)  { return String(""); }
  }
}

// ===========================================================================
//  Input: on-screen QWERTY keyboard
// ===========================================================================
//  Navigation : UP / DOWN / LEFT / RIGHT move the cursor across the keys.
//  Short OK    : type the highlighted key (or run the function key).
//  Short BACK  : backspace.
//  Long OK     : save / confirm the input.
//  Long BACK   : cancel out of the field.
//
//  Three character rows plus a function row. The function row keys are:
//    [cap]  toggle caps for letters
//    [123]  switch between letters and numbers/symbols
//    [spc]  insert a space
//    [del]  backspace
// ---------------------------------------------------------------------------
static const char* KB_LETTERS[3] = { "qwertyuiop", "asdfghjkl", "zxcvbnm" };
static const char* KB_SYMBOLS[3] = { "1234567890", "!@#$%^&*()", "-_=+.,?/:;" };

// Length of the currently active grid row (row 3 is the 4-key function row).
static int kbRowLen(int row, int layer) {
  if (row < 3) return (int)strlen(layer == 0 ? KB_LETTERS[row] : KB_SYMBOLS[row]);
  return 4;
}
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
void loop() {
  if (!g_unlocked) { unlockFlow(); return; }
  mainMenu();
}

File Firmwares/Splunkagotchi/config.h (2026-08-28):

// =============================================================================
//  config.h  -  Hardware pins and gameplay tuning for the WarPet firmware
//  Board: Seeed Studio XIAO ESP32-C5  (dual-band Wi-Fi 6 + BLE 5)
// =============================================================================
#pragma once

// ----------------------------------------------------------------------------
//  Buttons  (XIAO silkscreen labels -> Arduino D-macros defined by the variant).
//  Wired to GND, using internal pull-ups (active LOW).
// ----------------------------------------------------------------------------
#define PIN_BTN_UP     D0   // GPIO1
#define PIN_BTN_DOWN   D1   // GPIO0
#define PIN_BTN_OK     D2   // GPIO25
#define PIN_BTN_BACK   D3   // GPIO7
#define PIN_BTN_LEFT   D8   // GPIO8
#define PIN_BTN_RIGHT  D9   // GPIO9

// ----------------------------------------------------------------------------
//  OLED  (0.96" SSD1306, 128x64, I2C).  Default XIAO I2C = D4(SDA)/D5(SCL).
// ----------------------------------------------------------------------------
#define OLED_WIDTH     128
#define OLED_HEIGHT    64
#define OLED_ADDR      0x3C   // most 0.96" modules; some are 0x3D
#define OLED_ROTATION  2      // 0=normal, 2=180 (flipped)

// ----------------------------------------------------------------------------
//  Feature toggles
// ----------------------------------------------------------------------------
#define ENABLE_5G            1   // 5 GHz Wi-Fi scan pass
#define ENABLE_BLE           1   // BLE advertisement scanning
#define ENABLE_MONITOR       1   // passive promiscuous packet capture engine
#define ENABLE_WIGLE_UPLOAD  0   // deferred: needs GPS + home-Wi-Fi (see README)

// ----------------------------------------------------------------------------
//  Scanning
// ----------------------------------------------------------------------------
#define WIFI_SCAN_MS       260   // per-channel dwell for Wi-Fi scans (ms)
#define BLE_SCAN_MS        3000  // BLE active-scan window (ms)
#define SCAN_SHOW_HIDDEN   true

#define MAX_SEEN_AP        4000  // in-RAM uniqueness caps
#define MAX_SEEN_BLE       4000
#define MAX_SEEN_CLIENT    4000

// ----------------------------------------------------------------------------
//  Passive packet monitor (promiscuous). Purely observational: counts frames
//  and harvests unique client MACs from management/data frames. No injection.
// ----------------------------------------------------------------------------
#define MON_HOP_MS         300   // channel dwell before hopping (ms)
#define MON_CH_MIN         1     // 2.4 GHz channels to sweep in monitor mode
#define MON_CH_MAX         13
#define MON_ENERGY_MS      5000  // drain 1% energy per this interval while monitoring
#define XP_PER_PKT_BATCH   1     // +XP each time this many frames are seen
#define PKT_BATCH_SIZE     25

// ----------------------------------------------------------------------------
//  XP per discovery type (each unique thing found)
// ----------------------------------------------------------------------------
#define XP_PER_NEW_AP      10    // new access point (either band)
#define XP_PER_NEW_BLE     8     // new BLE device
#define XP_PER_NEW_CLIENT  12    // new Wi-Fi client station (from monitor)

// ----------------------------------------------------------------------------
//  Leveling: infinite, each level needs +15% more XP than the previous.
//  xpToNext(level) = XP_LEVEL_BASE * XP_LEVEL_GROWTH ^ level
// ----------------------------------------------------------------------------
#define XP_LEVEL_BASE      100.0f
#define XP_LEVEL_GROWTH    1.15f

// Evolution stages: one new stage every 5 levels (Egg/Baby/Teen/Adult).
//   Egg  L0-4 | Baby L5-9 | Teen L10-14 | Adult L15+
#define LVL_BABY           5     // egg hatches -> baby
#define LVL_TEEN           10    // Teen unlocks Packet Monitoring
#define LVL_ADULT          15    // Adult unlocks Promiscuous (client harvest)

// ----------------------------------------------------------------------------
//  Stats (all 0..100). NOTE: "hunger" here is a SATIATION meter -- high = well
//  fed. Discoveries raise it; inactivity lowers it (per the design spec).
// ----------------------------------------------------------------------------
#define STAT_TICK_MS       10000UL   // stat decay/update cadence

#define HUNGER_PER_DISCOVERY   4     // +satiation per new device discovered
#define HUNGER_DECAY_PER_TICK  2     // satiation lost each tick with no food

#define ENERGY_PER_DISCOVERY   3     // base energy gained per discovery
// Energy restore multiplier by hunger band (x100). 0-25 / 25-50 / 50-75 / 75-100
#define ENERGY_RATE_Q1     0         // hunger 0-25%   -> no restore
#define ENERGY_RATE_Q2     75        // hunger 25-50%  -> 75%
#define ENERGY_RATE_Q3     100       // hunger 50-75%  -> 100%
#define ENERGY_RATE_Q4     125       // hunger 75-100% -> 125%
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

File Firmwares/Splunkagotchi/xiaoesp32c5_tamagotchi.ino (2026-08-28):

// =============================================================================
//  WarPet  -  a dual-band Wi-Fi + BLE wardriving rig that is also a Tamagotchi
//  Target : Seeed Studio XIAO ESP32-C5  (2.4G + 5G Wi-Fi 6, BLE 5)
//  Display: 0.96" SSD1306 128x64 OLED (I2C)
//  Input  : 6 buttons (UP/DOWN/OK/BACK/LEFT/RIGHT)
//
//  The creature earns XP from every UNIQUE discovery: Wi-Fi APs (2.4/5 GHz),
//  BLE devices, and Wi-Fi client stations harvested by the passive monitor.
//  Captures are logged to an on-device ring buffer (oldest overwritten when
//  full). Home-Wi-Fi + Wigle credentials are configured over USB serial and
//  kept in NVS for a future Wigle uploader (currently disabled: needs GPS).
//
//  SCOPE / SAFETY: this firmware is PASSIVE. It listens to broadcast beacons
//  and advertisements and, in monitor mode, observes over-the-air 802.11
//  frames to count packets and collect device MAC addresses. It does NOT
//  transmit deauthentication frames, inject packets, connect to foreign
//  networks, or capture payloads. There is intentionally no deauth attack
//  capability. Operate only where passive monitoring is lawful.
//
//  Libraries: Adafruit SSD1306, Adafruit GFX, NimBLE-Arduino (v2.x).
//  Board support: esp32 by Espressif Systems, v3.1.0+ (C5 + 5 GHz + monitor).
// =============================================================================

#include "config.h"      // defines feature toggles used by the guards below

#include <Wire.h>
#include <Adafruit_GFX.h>
#include <Adafruit_SSD1306.h>
#include <Fonts/Org_01.h>
#include <WiFi.h>
#include <Preferences.h>
#include <LittleFS.h>
#include <esp_wifi.h>
#include <esp_random.h>
#include <set>
#include <map>
#include <string>
#include <math.h>

#if ENABLE_BLE
  #include <NimBLEDevice.h>
#endif

#include "names.h"
#include "sprites.h"

// =============================================================================
//  Types  (defined before any function so the Arduino auto-prototype pass,
//  which hoists prototypes above the first function, can see them).
// =============================================================================
enum Stage  { EGG = 0, BABY, TEEN, ADULT };
enum Screen { SC_HOME, SC_STATS, SC_LOG, SC_MENU };
enum Mode   { MODE_SCAN, MODE_MONITOR, MODE_PROMISC };
enum ScanState {
  S_IDLE, S_W2G_START, S_W2G_WAIT, S_W5G_START, S_W5G_WAIT,
  S_BLE_START, S_BLE_WAIT, S_COOLDOWN
};

// Capture record type tags.
enum RecType { RT_AP2G = 0, RT_AP5G = 1, RT_BLE = 2, RT_CLIENT = 3 };

struct __attribute__((packed)) Rec {
  uint32_t ts;         // seconds since boot
  uint8_t  type;       // RecType
  uint8_t  mac[6];
  int8_t   rssi;
  uint8_t  channel;
  char     ssid[24];   // AP name / BLE name (truncated); empty for clients
};

struct Button {
  uint8_t  pin;
  bool     last      = false;
  bool     pressedEv = false;
  uint32_t tChange   = 0;
  uint32_t tRepeat   = 0;
};

struct CliObs { int8_t rssi; uint8_t ch; };  // staged client observation
struct MItem  { const char* label; int id; };  // one menu row

// =============================================================================
//  Globals
// =============================================================================
Adafruit_SSD1306 oled(OLED_WIDTH, OLED_HEIGHT, &Wire, -1);
Preferences      prefs;

// Uniqueness sets (MAC packed into uint64).
std::set<uint64_t> seenAP, seenBLE, seenClient;

// Pet / save state.
struct Pet {
  char     name[16] = "";
  uint32_t xp       = 0;     // XP into the current level
  uint16_t level    = 0;     // 0 = egg
  uint8_t  hunger   = 60;    // SATIATION: 100 = well fed, 0 = starving
  uint8_t  energy   = 80;
  uint8_t  petComp  = 50;    // "pet" component of mood (0..100)
  uint32_t bornMs   = 0;
  uint32_t ageSec   = 0;     // accumulated powered-on lifetime, in seconds
} pet;

int      activity = 30;      // recent-discovery component of mood (0..100)
uint32_t uniqueAP = 0, uniqueBLE = 0, uniqueClient = 0;   // NVS backups

// Lifetime packet counter (pktCount is session-only; this persists the total).
uint32_t lifetimePkts  = 0;  // packets counted before this session
uint32_t lastSavedPkts = 0;  // session marker used to roll pktCount into the total

// Runtime config (from serial, stored in NVS namespace "cfg").
String cfgHomeSSID, cfgHomePass, cfgWigleName, cfgWigleToken;

// UI / mode.
Screen   screen = SC_HOME;
Mode     mode   = MODE_SCAN;
bool     scanPaused = false;
int      menuIdx = 0, menuTop = 0;
bool     confirmReset = false;
String   bubble; uint32_t bubbleUntil = 0;
bool     levelUpFlag = false;
const char* bandLabel = "--";

// Scanner state.
ScanState scanState = S_IDLE;
uint32_t  scanTimer = 0;
uint32_t  lastNew2G = 0, lastNew5G = 0, lastNewBLE = 0, lastNewClient = 0;

// Monitor engine.
volatile uint32_t pktCount = 0;        // frames seen (monitor)
uint32_t pktBatchMark = 0;
uint8_t  monChannel = MON_CH_MIN;
uint32_t monHopTimer = 0, monEnergyTimer = 0;
SemaphoreHandle_t monMutex = nullptr;
std::map<uint64_t, CliObs> cliStaging; // filled by promisc cb, drained in loop

// Storage ring.
File     storeFile;
uint32_t storeHead = 0, storeCount = 0;
const uint32_t RECORD_SIZE = sizeof(Rec);

// =============================================================================
//  Small helpers
// =============================================================================
static uint64_t macToU64(const uint8_t* m) {
  uint64_t v = 0;
  for (int i = 0; i < 6; i++) v = (v << 8) | m[i];
  return v;
}
static void u64ToMac(uint64_t v, uint8_t* m) {
  for (int i = 5; i >= 0; i--) { m[i] = v & 0xFF; v >>= 8; }
}
static uint64_t macStrToU64(const std::string& s) {
  uint8_t b[6] = {0}; int idx = 0; unsigned int hi, lo;
  const char* p = s.c_str();
  while (*p && idx < 6) {
    if (sscanf(p, "%1x%1x", &hi, &lo) == 2) { b[idx++] = (uint8_t)((hi << 4) | lo); p += 2; }
    if (*p == ':') p++; else if (*p == '\0') break; else p++;
  }
  return macToU64(b);
}

static uint32_t xpToNext(uint16_t level) {
  double v = (double)XP_LEVEL_BASE * pow((double)XP_LEVEL_GROWTH, (double)level);
  if (v > 4.0e9) return 0xFFFFFFFFUL;
  return (uint32_t)(v + 0.5);
}

static Stage stageForLevel(uint16_t lvl) {
  if (lvl < LVL_BABY) return EGG;    // one stage per 5 levels
  if (lvl < LVL_TEEN) return BABY;
  if (lvl < LVL_ADULT) return TEEN;
  return ADULT;
}
static const char* stageName(Stage s) {
  switch (s) {
    case EGG:  return "Egg";
    case BABY: return "Baby";
    case TEEN: return "Teen";
    default:   return "Adult";
  }
}
static bool monitorUnlocked()  { return pet.level >= LVL_TEEN; }
static bool promiscUnlocked()  { return pet.level >= LVL_ADULT; }

static uint32_t lifetimePktTotal() { return lifetimePkts + (pktCount - lastSavedPkts); }
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

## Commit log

2026-08-22 Create README.md for Spunkleboard project
    Added detailed README for Spunkleboard development board including features, hardware overview, getting started guide, and contribution instructions.
2026-08-28 A list of template firmwares made for the board.
2026-08-28 Add button wiring section to README
    Added button wiring information to the README.
